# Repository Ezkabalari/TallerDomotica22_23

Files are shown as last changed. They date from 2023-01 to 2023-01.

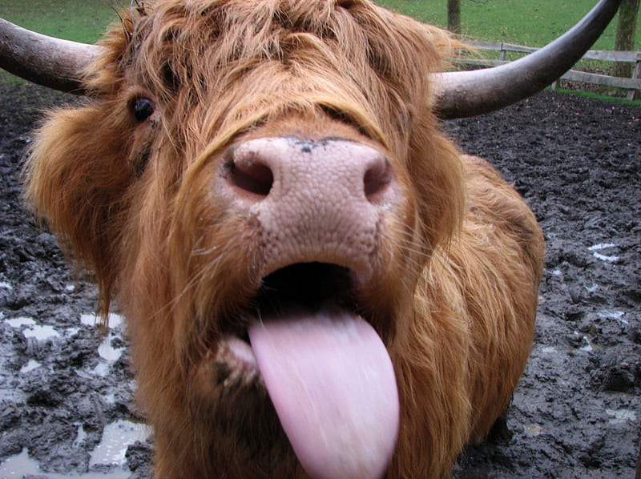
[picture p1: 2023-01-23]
RPi_HMI/web_ui/images/highcow.jpg

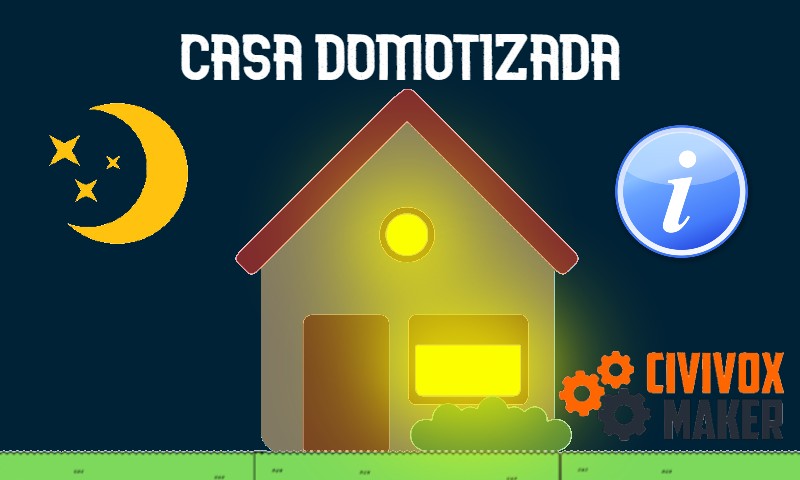
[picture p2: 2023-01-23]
imagenes/1 -2.jpg

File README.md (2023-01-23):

# TallerDomotica22_23
Smart Home

Sketches y scripts del taller de domótica dado en Civivox Mendillorri de Octubre 2022 a Febrero 2023. Para la creación de una maqueta de una casa inteligente.
Tambien se añade una carpeta para recrear la Funcionalidad de la pantalla de control en una pagina web alojada en una raspberry pi.

# Enlaces Interesantes
* Controlar un motor de pasos: https://github.com/cv47522/nodejs-j5-arduino-stepper
* Plataforma para controlar Placas como arduino desde una web con Javascript: https://johnny-five.io/

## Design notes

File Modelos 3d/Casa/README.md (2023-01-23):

Estos modelos 3D han sido creados por Aimar Romeo en Autodesk Inventor 2019.
Impresos en PLA de SmartMaterials (PLA Recycled azul claro) con los siguientes parámetros:

Impresoras: Clon Prusa MK3S+ con marco BEAR y Artillery Sidewinder X1 (Extrusor E3D Hemera).
Boquilla: 	0.4mm
Altura de capa: 0.2mm
Relleno: 	15%
Velocidad: 	60mm/s
Temperatura: 	200ºC
Soportes:	Sí. En todos los sitios.

Nota: Los modelos están escalados para imprimir una casa de 400x400mm

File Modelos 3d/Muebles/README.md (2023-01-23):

Estos modelos 3D han sido creados por Argoroots y descargados desde Printables.com
Gracias a su trabajo por estos modelos 3D tan maravillosos.

Nota: Los modelos 3D están escalados al tamaño original de la casa (400x400mm)

Enlace a Printables: https://www.printables.com/es/model/112496-dollhouse-furniture/files

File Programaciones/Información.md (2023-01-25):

Utilizar las siguientes líneas para cambiar de fondo/imagen en cada pantalla de la nextion.

Si está configurada como fondo de la página: //Ésto es importante, de ser una imagen y no un fondo, los botones/textos/íconos... "Desaparecerán" de la pantalla
página.pic=id de la foto
menu.pic=0

Para mandar datos desde arduino:
Serial.print ("menu.pic=0");
Serial.write(0xff);
Serial.write(0xff);
Serial.write(0xff);

Si queremos cambiar el fondo según el valor del sensor:
if (valor_sensor >= valor_medio){
  Serial.print ("menu.pic=0");
  Serial.write(0xff);
  Serial.write(0xff);
  Serial.write(0xff);
}
else(){
  Serial.print ("menu.pic=1");
  Serial.write(0xff);
  Serial.write(0xff);
  Serial.write(0xff);
}

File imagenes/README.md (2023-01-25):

Imagenes creadas por Aimar Romeo para el proyecto de domótica en Civivox Mendillorri 2023

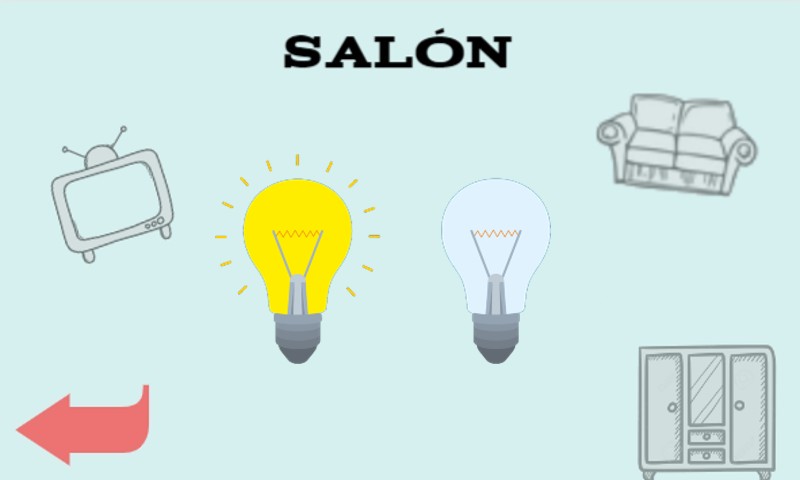
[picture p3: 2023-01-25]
imagenes/salon.jpg

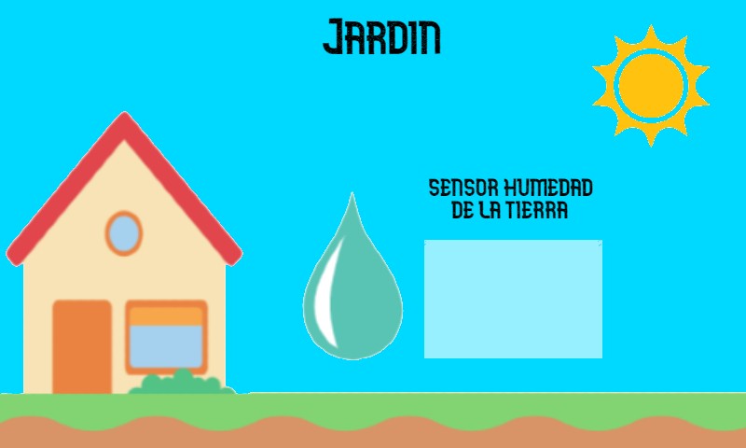
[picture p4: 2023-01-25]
imagenes/Jardin dia.jpg

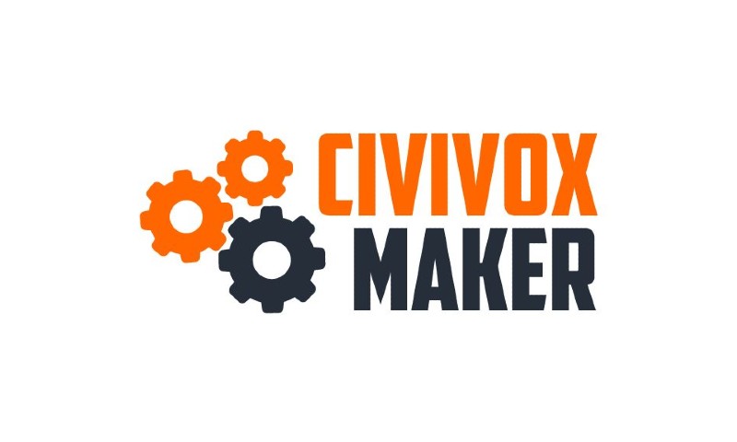
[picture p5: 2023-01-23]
imagenes/Pantalla de carga.jpg

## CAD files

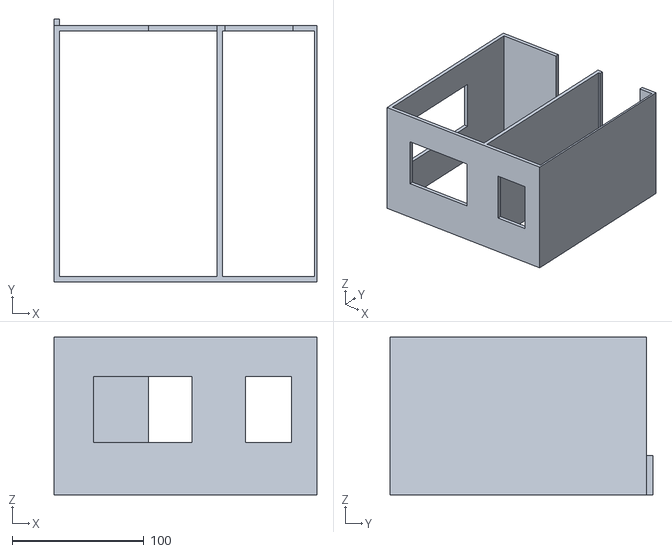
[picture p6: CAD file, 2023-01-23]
Modelos 3d/Casa/Parte 3.stl
200.0 x 200.0 x 120.0

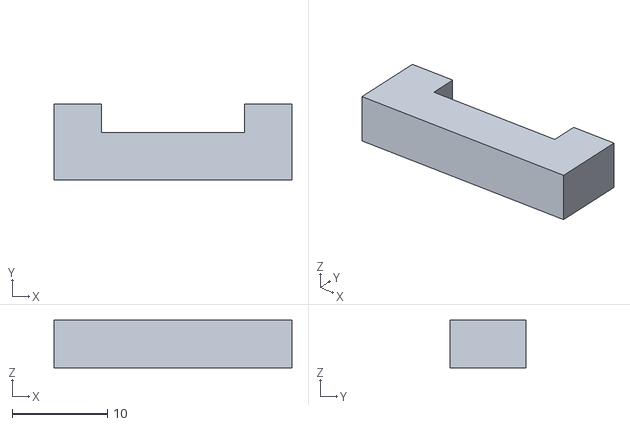
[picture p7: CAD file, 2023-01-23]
Modelos 3d/Muebles/Armario/Armario-Pata x2.stl
25.0 x 8.00 x 5.00

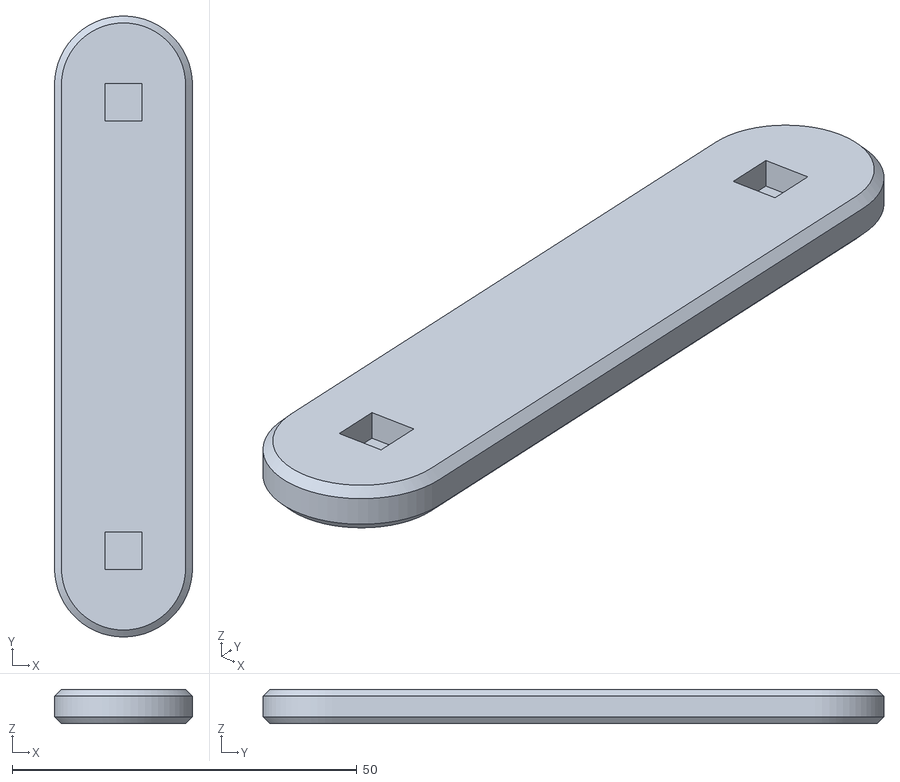
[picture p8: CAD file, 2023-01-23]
Modelos 3d/Muebles/Cama/Cama-Respaldo.stl
20.0 x 90.0 x 5.00

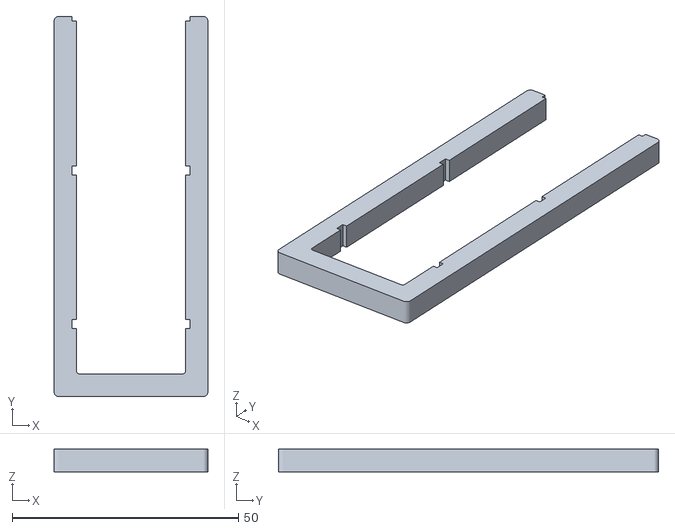
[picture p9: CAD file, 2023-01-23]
Modelos 3d/Muebles/Estantería/Estantería-Pata x2.stl
34.0 x 84.0 x 5.00

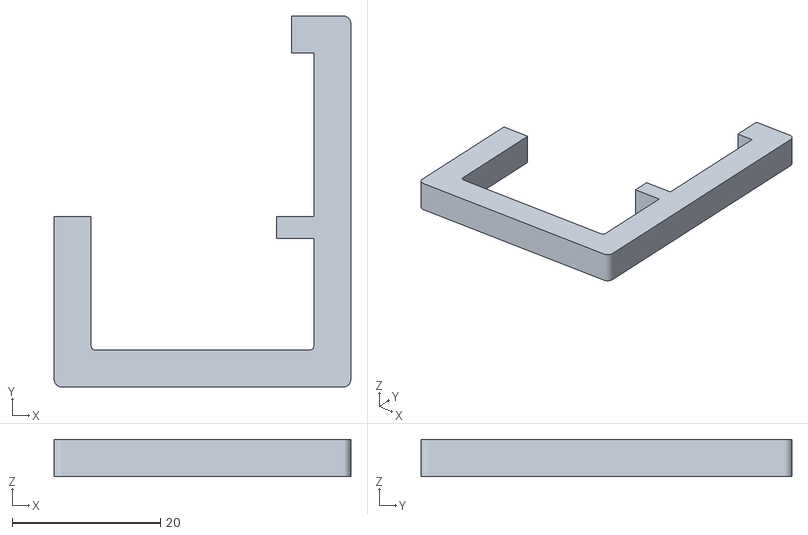
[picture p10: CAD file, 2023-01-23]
Modelos 3d/Muebles/Silla/Silla-Pata x2.stl
40.0 x 50.0 x 5.00

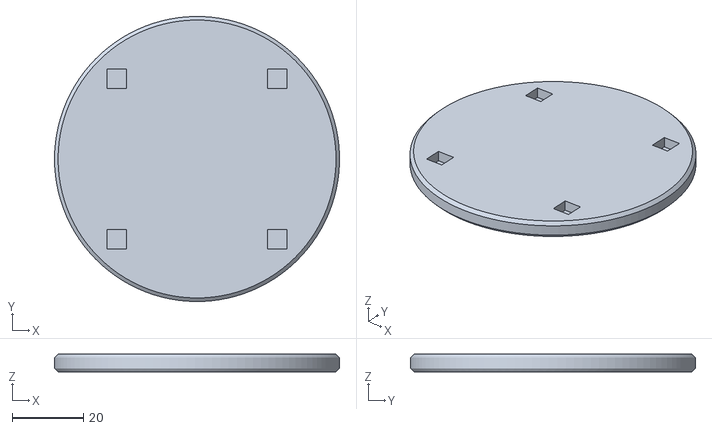
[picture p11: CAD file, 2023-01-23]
Modelos 3d/Muebles/Table/Mesa.stl
80.0 x 80.0 x 5.00

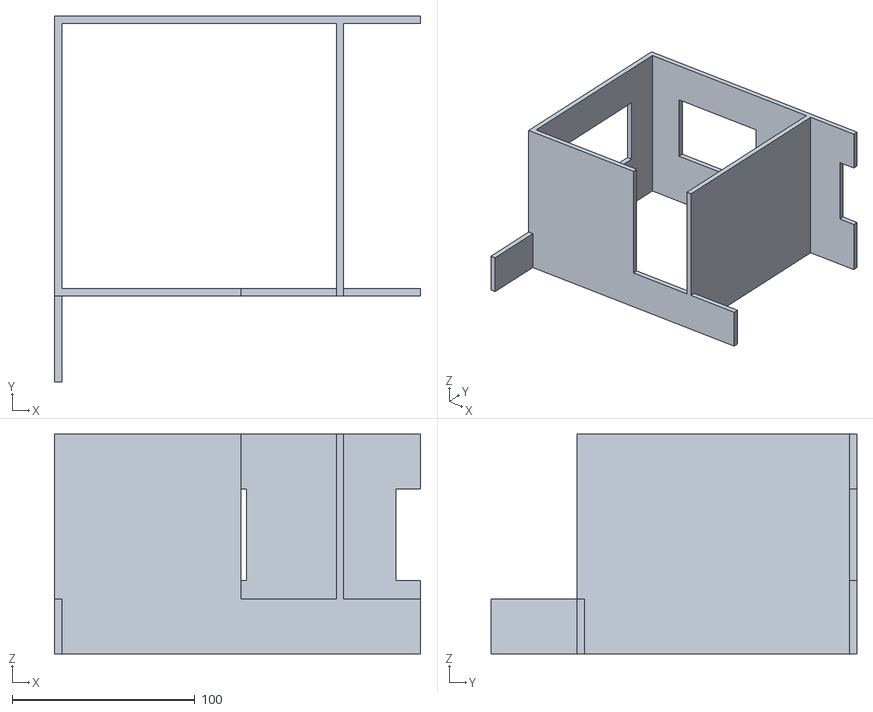
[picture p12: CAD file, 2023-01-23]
Modelos 3d/Casa/Parte 1.stl
200.0 x 200.0 x 120.0

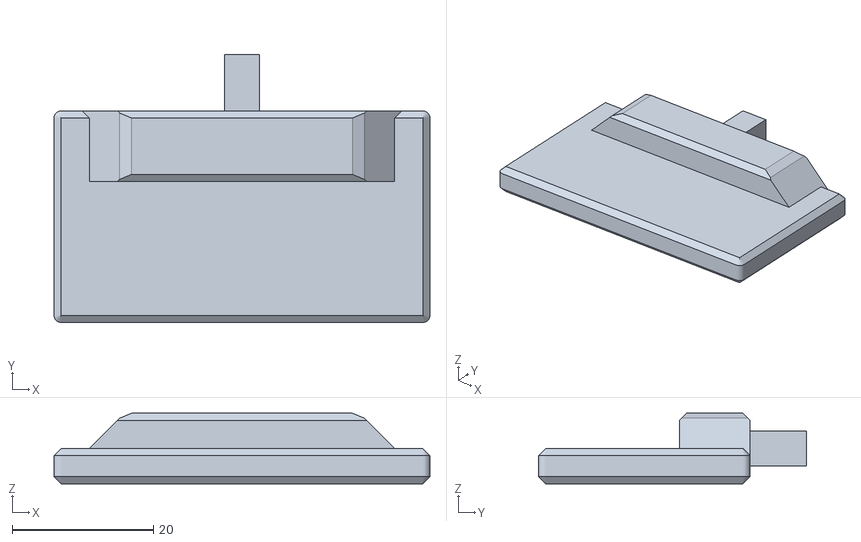
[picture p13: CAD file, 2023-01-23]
Modelos 3d/Muebles/Armario/Televisión.stl
53.3 x 38.0 x 10.0

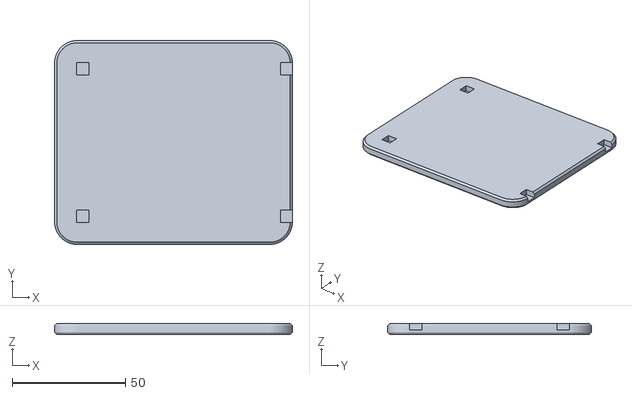
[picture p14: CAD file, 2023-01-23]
Modelos 3d/Muebles/Cama/Cama.stl
105.0 x 90.0 x 5.00

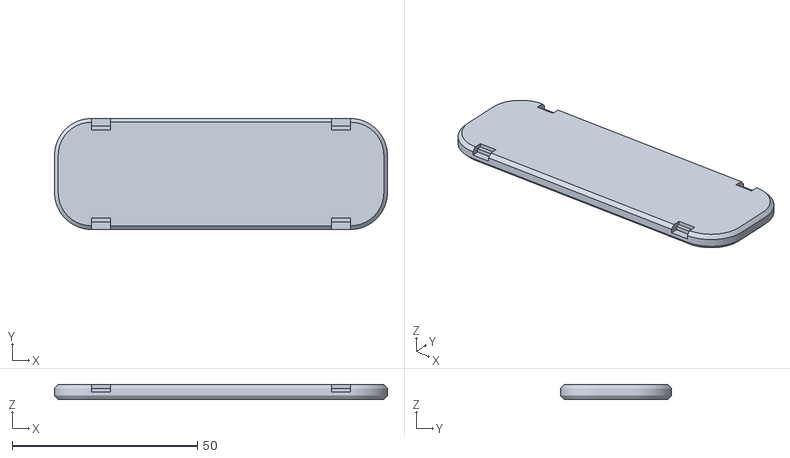
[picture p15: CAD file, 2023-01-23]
Modelos 3d/Muebles/Estantería/Estantería-Superior.stl
90.0 x 30.0 x 4.00

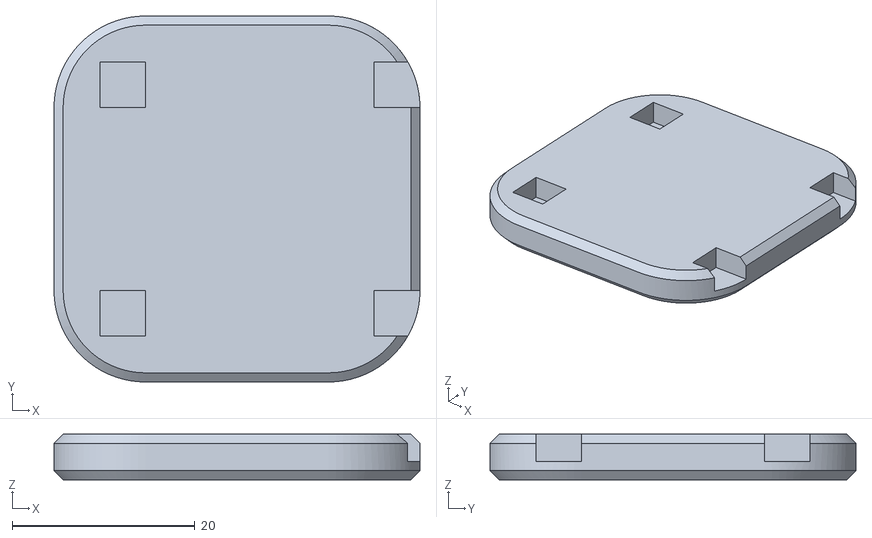
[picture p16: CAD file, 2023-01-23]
Modelos 3d/Muebles/Silla/Silla.stl
40.0 x 40.0 x 5.00

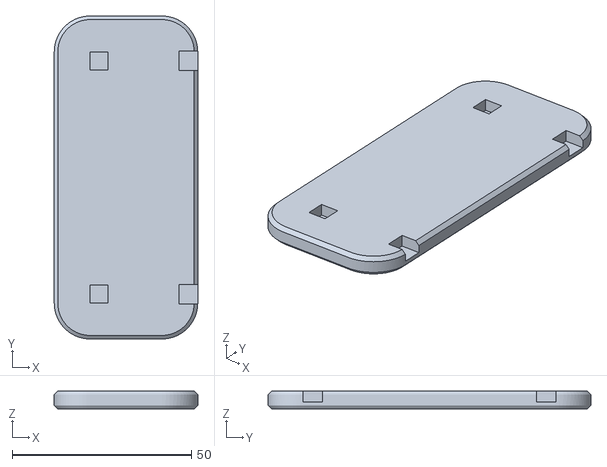
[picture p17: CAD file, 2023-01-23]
Modelos 3d/Muebles/Sofa/Sofa.stl
40.0 x 90.0 x 5.00

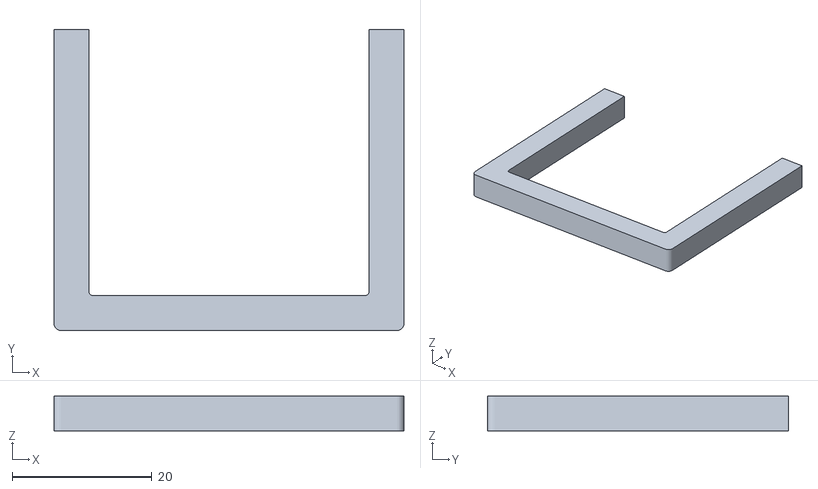
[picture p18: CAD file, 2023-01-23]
Modelos 3d/Muebles/Table/Mesa-Pata x2.stl
50.0 x 43.0 x 5.00

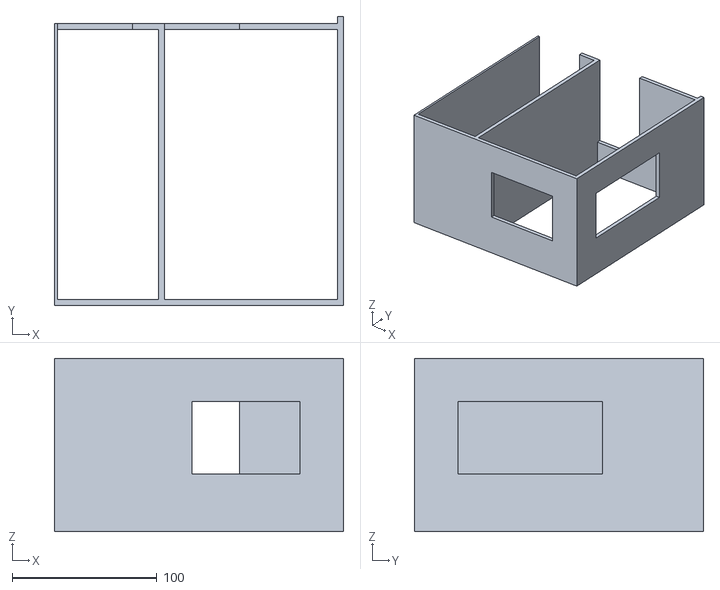
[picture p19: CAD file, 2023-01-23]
Modelos 3d/Casa/Parte 4.stl
200.0 x 200.0 x 120.0

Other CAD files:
Modelos 3d/Muebles/Armario/Armario.stl
Modelos 3d/Muebles/Cama/Cama-Pata x2.stl
Modelos 3d/Muebles/Estantería/Estantería.stl
Modelos 3d/Casa/Casa - Proyecto Inventor 2019.ipt
Modelos 3d/Casa/Casa completa.stl
Modelos 3d/Casa/Parte 2.stl
Modelos 3d/Muebles/Silla/Silla-Respaldo.stl
Modelos 3d/Muebles/Sofa/Sofa-Almohada x2.stl
Modelos 3d/Muebles/Sofa/Sofa-Pata x2.stl

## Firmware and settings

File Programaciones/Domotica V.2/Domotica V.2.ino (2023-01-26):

/*
 * Pines de conexionado a arduino UNO:
 * 
 * A0: Sensor de gas para la cocina           (MQ-02)
 * A1: Sensor de humedad de la tierra         (Higrometro V1.2)
 * A2: Sensor de luz para garaje              (KY-018)
 * A3: Sensor de luz para exterior            (KY-018)
 * A4: Sensor de temperatura de habitación 1  (LM35)
 * A5: ///////////////////////////////////////////////////////////////////////////////////////////////
 * D0: Nextion cable azul                     (Nextion NX8048T050)
 * D1: Nextion cable amarillo                 (Nextion NX8048T050)
 * D2: Leds Habitación 1                      (Led amarillo 5mm)
 * D3: Leds Baño                              (Led amarillo 5mm)
 * D4: Leds Cuarto lavadora                   (Led amarillo 5mm)
 * D5: Leds Habitación 2                      (Led amarillo 5mm)
 * D6: Leds Pasillo                           (Led amarillo 5mm)
 * D7: Leds Cocina                            (Led amarillo 5mm)
 * D8: Leds Salón                             (Led amarillo 5mm)
 * D9: Leds Gimnasio                          (Led amarillo 5mm)
 * D10: Sensor de presencia del pasillo       (HC-SR505)
 * D11: Servomotor de la puerta principal     (SG-90)
 * D12: Ventilador de la habitación 1         (Noctua NF-A4x10)
 * D13: Bomba de agua de la tierra            (Bomba de agua de 12v)
 */

/* 
DATOS MANDADOS DE NEXTION A ARDUINO

NAME     |  ON    |  OFF   |  description
=====================================================
lall     |  100   |  101   |  luces de toda la casa
lh1      |  102   |  103   |  luces habitación 1
lwc      |  104   |  105   |  luces baño
llav     |  106   |  107   |  luces lavadora
lh2      |  108   |  109   |  luces habitación 2
lco      |  110   |  111   |  luces cocina
lpas     |  112   |  113   |  luces pasillo
lgym     |  114   |  115   |  luces gimnasio
lsal     |  116   |  117   |  luces salón
bven     |  200   |        |  botón ventilador
bag      |  201   |        |  botón agua
bpu      |  202   |        |  botón puerta
bal      |  203   |  204   |  botón alarma



DATOS MANDADOS DE ARDUINO A NEXTION
variable |    sensor   | lugar
=======================================
stem     | temperatura | habitación 1
sgas     |     gas     | cocina
ssum     |   humedad   | jardín
spir     |  movimiento | pasillo
sldr     |     LDR     | menú
sppal    |     LDR     | puerta principal

*/
// LIBRERÍAS
#include <Servo.h>


//PINES UTILIZADOS
int rele_bomba = 13;                              //Configuramos la salida digital 13 para el relé que controla la bomba de agua
int rele_ventilador = 12;                         //Configuramos la salida digital 12 para el relé que controla el ventilador
Servo puerta_principal;                           //Los servos se configuran en el void setup
int sensor_PIR = 10;                              //Configuramos la entrada digital 4 para el sensor de movimiento
int led_gimnasio = 9;                             //Configuramos la salida digital 9 para la luz del gimnasio
int led_salon = 8;                                //Configuramos la salida digital 8 para la luz del salón
int led_cocina = 7;                               //Configuramos la salida digital 7 para la luz de la cocina
int led_pasillo = 6;                              //Configuramos la salida digital 6 para la luz del pasillo
int led_hab2 = 5;                                 //Configuramos la salida digital 5 para la luz de la habitación 2
int led_lavadora = 4;                             //Configuramos la salida digital 4 para la luz del cuarto de la lavadora
int led_wc = 3;                                   //Configuramos la salida digital 3 para la luz del baño
int led_hab1 = 2;                                 //Configuramos la salida digital 2 para la luz de la habitación 1
// Pin 1 reservado para Nextion                   //Arduino trae por defecto éste pin para la transmisión de datos
// Pin 0 reservado para Nextion                   //Arduino trae por defecto éste pin para la recepción de datos
int sensor_temperatura = A4;                      //Configuramos la entrada analógica 4 para el sensor de temperatura
int sensor_luz = A3;                              //Configuramos la entrada analógica 3 para el sensor de luz
int sensor_puerta = A2;                           //Configuramos la entrada analógica 2 para el sensor de luz
int sensor_tierra = A1;                           //Configuramos la entrada analógica 1 para el sensor de humedad
int sensor_gas = A0;                              //Configuramos la entrada analógica 0 para el sensor de gas

int Valarma = 0;

void setup() {
  Serial.begin (9600);                            //Iniciamos la comunicación serial a 9600 baudios para la comunicación con la pantalla Nextion
  pinMode (rele_bomba, OUTPUT);                   //Definimos como SALIDA el pin conectado al relé que controla la bomba de agua
  pinMode (rele_ventilador, OUTPUT);              //Definimos como SALIDA el pin conectado al relé que controla el ventilador
  puerta_principal.attach (11);                   //Configuramos la SALIDA 11 para el servo de la puerta principal
  pinMode (led_gimnasio, OUTPUT);                 //Definimos como SALIDA el pin conectado a la luz del gimnasio
  pinMode (led_salon, OUTPUT);                    //Definimos como SALIDA el pin conectado a la luz del salon
  pinMode (led_cocina, OUTPUT);                   //Definimos como SALIDA el pin conectado a la luz de la cocina
  pinMode (led_pasillo, OUTPUT);                  //Definimos como SALIDA el pin conectado a la luz del pasillo
  pinMode (led_hab2, OUTPUT);                     //Definimos como SALIDA el pin conectado a la luz de la habitación 2
  pinMode (led_lavadora, OUTPUT);                 //Definimos como SALIDA el pin conectado a la luz del cuarto de la lavadora
  pinMode (led_wc, OUTPUT);                       //Definimos como SALIDA el pin conectado a la luz del baño
  pinMode (led_hab1, OUTPUT);                     //Definimos como SALIDA el pin conectado a la luz de la habitación 1
  pinMode (sensor_temperatura, INPUT);            //Definimos como ENTRADA el pin conectado al sensor de temperatura
  pinMode (sensor_PIR, INPUT);                    //Definimos como ENTRADA el pin conectado al sensor de presencia
  pinMode (sensor_luz, INPUT);                    //Definimos como ENTRADA el pin conectado al sensor de luz del exterior
  pinMode (sensor_puerta, INPUT);                 //Definimos como ENTRADA el pin conectado al sensor de luz de la puerta principal
  pinMode (sensor_tierra, INPUT);                 //Definimos como ENTRADA el pin conectado al sensor de humedad de la tierra
  pinMode (sensor_gas, INPUT);                    //Definimos como ENTRADA el pin conectado al sensor de gases


  puerta_principal.write(0);                      //Movemos el servomotor a su posición inicial
  digitalWrite (led_gimnasio, LOW);               //Apagamos los leds del gimnasio
  digitalWrite (led_salon, LOW);                  //Apagamos los leds del salón
  digitalWrite (led_cocina, LOW);                 //Apagamos los leds de la cocina
  digitalWrite (led_pasillo, LOW);                //Apagamos los leds del pasillo
  digitalWrite (led_hab2, LOW);                   //Apagamos los leds de la habitación 2
  digitalWrite (led_lavadora, LOW);               //Apagamos los leds del cuarto de la lavadora
  digitalWrite (led_wc, LOW);                     //Apagamos los leds del baño
  digitalWrite (led_hab1, LOW);                   //Apagamos los leds de la habitación 1
  
}

void loop() {
  int Vstem = analogRead (sensor_temperatura);    //Definimos una variable a la cual asignamos el valor de lectura del sensor de temperatura
  int Vspir = analogRead (sensor_PIR);            //Definimos una variable a la cual asignamos el valor de lectura del sensor de movimiento
  int Vsldr = analogRead (sensor_luz);            //Definimos una variable a la cual asignamos el valor de lectura del sensor de luz exterior
  int Vsppal = analogRead (sensor_puerta);        //Definimos una variable a la cual asignamos el valor de lectura del sensor de luz entrada
  int Vshum = analogRead (sensor_tierra);         //Definimos una variable a la cual asignamos el valor de lectura del sensor de humedad del suelo
  int Vsgas = analogRead (sensor_gas);            //Definimos una variable a la cual asignamos el valor de lectura del sensor de gas
  int milivoltios = (Vstem / 1023.0) * 5000;
  int Vstemm = (milivoltios / 10);
  int Vdalarma = digitalRead (sensor_PIR);
  int estado_pir = LOW;
  
  String lectura = Serial.readString();           //Definimos la variable lectura que será con la cual recogeremos el valor de la pantalla
  
  if (int(lectura[0]) == 100){
      digitalWrite (led_gimnasio, HIGH);          //Encendemos los leds del gimnasio
      digitalWrite (led_salon, HIGH);             //Encendemos los leds del salón
      digitalWrite (led_cocina, HIGH);            //Encendemos los leds de la cocina
      digitalWrite (led_pasillo, HIGH);           //Encendemos los leds del pasillo
      digitalWrite (led_hab2, HIGH);              //Encendemos los leds de la habitación 2
      digitalWrite (led_lavadora, HIGH);          //Encendemos los leds del cuarto de la lavadora
      digitalWrite (led_wc, HIGH);                //Encendemos los leds del baño
      digitalWrite (led_hab1, HIGH);              //Encendemos los leds de la habitación 1
    }
  if (int(lectura[0]) == 101){
      digitalWrite (led_gimnasio, LOW);           //Apagamos los leds del gimnasio
      digitalWrite (led_salon, LOW);              //Apagamos los leds del salón
      digitalWrite (led_cocina, LOW);             //Apagamos los leds de la cocina
      digitalWrite (led_pasillo, LOW);            //Apagamos los leds del pasillo
      digitalWrite (led_hab2, LOW);               //Apagamos los leds de la habitación 2
      digitalWrite (led_lavadora, LOW);           //Apagamos los leds del cuarto de la lavadora
      digitalWrite (led_wc, LOW);                 //Apagamos los leds del baño
      digitalWrite (led_hab1, LOW);               //Apagamos los leds de la habitación 1
    }
  if (int(lectura[0]) == 102){
      digitalWrite (led_hab1, HIGH);              //Encendemos los leds de la habitación 1
    }
  if (int(lectura[0]) == 103){
      digitalWrite (led_hab1, LOW);               //Apagamos los leds de la habitación 1
    }
  if (int(lectura[0]) == 104){
      digitalWrite (led_wc, HIGH);                //Encendemos los leds del baño
    }
  if (int(lectura[0]) == 105){
      digitalWrite (led_wc, LOW);                 //Apagamos los leds del baño
    }
  if (int(lectura[0]) == 106){
      digitalWrite (led_lavadora, HIGH);          //Encendemos los leds del cuarto de la lavadora
    }
  if (int(lectura[0]) == 107){
      digitalWrite (led_lavadora, LOW);           //Apagamos los leds del cuarto de la lavadora
    }
  if (int(lectura[0]) == 108){
      digitalWrite (led_hab2, HIGH);              //Encendemos los leds de la habitación 2
    }
  if (int(lectura[0]) == 109){
      digitalWrite (led_hab2, LOW);               //Apagamos los leds de la habitación 2
    }
  if (int(lectura[0]) == 110){
      digitalWrite (led_cocina, HIGH);            //Encendemos los leds de la cocina
    }
  if (int(lectura[0]) == 111){
      digitalWrite (led_cocina, LOW);             //Apagamos los leds de la cocina
    }
  if (int(lectura[0]) == 112){
      digitalWrite (led_pasillo, HIGH);           //Encendemos los leds del pasillo
    }
  if (int(lectura[0]) == 113){
      digitalWrite (led_pasillo, LOW);            //Apagamos los leds del pasillo
    }
  if (int(lectura[0]) == 114){
      digitalWrite (led_gimnasio, HIGH);          //Encendemos los leds del gimnasio
    }
  if (int(lectura[0]) == 115){
      digitalWrite (led_gimnasio, LOW);           //Apagamos los leds del gimnasio
    }
  if (int(lectura[0]) == 116){
      digitalWrite (led_salon, HIGH);             //Encendemos los leds del salón
    }
  if (int(lectura[0]) == 117){
      digitalWrite (led_salon, LOW);              //Apagamos los leds del salón
    }
  if (int(lectura[0]) == 200){
      digitalWrite (rele_ventilador, HIGH);       //Encendemos el relé del ventilador
      delay (5000);
      digitalWrite (rele_ventilador, LOW);        //Apagamos el relé del ventilador
    }
  if (int(lectura[0]) == 201){
      digitalWrite (rele_bomba, HIGH);            //Encendemos el relé de la bomba de agua
      delay (5000);
      digitalWrite (rele_bomba, LOW);             //Apagamos el relé de la bomba de agua
    }   
  if (int(lectura[0]) == 202){
      puerta_principal.write(90);                 //Movemos el servomotor a su posición abierta
      delay (2500);
      puerta_principal.write(0);                  //Movemos el servomotor a su posición cerrada
    }
  if (int(lectura[0]) == 203){
      Valarma = 1;                                //Asignamos un 1 al estado de la alarma
    }
  if (int(lectura[0]) == 204){
      Valarma = 0;                                //Asignamos un 0 al estado de la alarma
    }
  if (Valarma = 1){                               //Si el estado de la alarma es 1, entonces...
      if (Vdalarma == HIGH){                      //Si el sensor de movimiento detecta movimiento, entonces...
        digitalWrite (led_gimnasio, HIGH);        //Encendemos los leds del gimnasio
        digitalWrite (led_salon, HIGH);           //Encendemos los leds del salón
        digitalWrite (led_cocina, HIGH);          //Encendemos los leds de la cocina
        digitalWrite (led_pasillo, HIGH);         //Encendemos los leds del pasillo
        digitalWrite (led_hab2, HIGH);            //Encendemos los leds de la habitación 2
        digitalWrite (led_lavadora, HIGH);        //Encendemos los leds del cuarto de la lavadora
        digitalWrite (led_wc, HIGH);              //Encendemos los leds del baño
        digitalWrite (led_hab1, HIGH);            //Encendemos los leds de la habitación 1
        delay (100);                              //Espera de 0,1s para hacer parpadeo
        digitalWrite (led_gimnasio, LOW);         //Apagamos los leds del gimnasio
        digitalWrite (led_salon, LOW);            //Apagamos los leds del salón
        digitalWrite (led_cocina, LOW);           //Apagamos los leds de la cocina
        digitalWrite (led_pasillo, LOW);          //Apagamos los leds del pasillo
        digitalWrite (led_hab2, LOW);             //Apagamos los leds de la habitación 2
        digitalWrite (led_lavadora, LOW);         //Apagamos los leds del cuarto de la lavadora
        digitalWrite (led_wc, LOW);               //Apagamos los leds del baño
        digitalWrite (led_hab1, LOW);             //Apagamos los leds de la habitación 1
        delay (100);                              //Espera de 0,1s para hacer parpadeo
      }
      else {                                      //Sino...
        digitalWrite (led_gimnasio, LOW);         //Apagamos los leds del gimnasio
        digitalWrite (led_salon, LOW);            //Apagamos los leds del salón
        digitalWrite (led_cocina, LOW);           //Apagamos los leds de la cocina
        digitalWrite (led_pasillo, LOW);          //Apagamos los leds del pasillo
        digitalWrite (led_hab2, LOW);             //Apagamos los leds de la habitación 2
        digitalWrite (led_lavadora, LOW);         //Apagamos los leds del cuarto de la lavadora
        digitalWrite (led_wc, LOW);               //Apagamos los leds del baño
        digitalWrite (led_hab1, LOW);             //Apagamos los leds de la habitación 1
        }
    } 
    if(Vshum < 500)
    {
      digitalWrite (rele_bomba, HIGH);
      delay (5000);
      digitalWrite (rele_bomba, LOW);
    }
    if (Vsppal < 750){
      puerta_principal.write(90);                 //Movemos el servomotor a su posición abierta
      delay (2500);
      puerta_principal.write(0);                  //Movemos el servomotor a su posición cerrada
    }
    if (Vsgas < 750){
      puerta_principal.write(90);                 //Movemos el servomotor a su posición abierta
      delay (2500);
      puerta_principal.write(0);                  //Movemos el servomotor a su posición cerrada
    }
    if (Vsldr <= 400){
      Serial.print ("menu.pic=1");
      Serial.write(0xff);
      Serial.write(0xff);
      Serial.write(0xff);
    }
    else {
      Serial.print ("menu.pic=0");
      Serial.write(0xff);
      Serial.write(0xff);
      Serial.write(0xff);
    }
  delay (2500);
  
  Serial.print ("stem.val=");                     //Enviamos datos del sensor de temperatura a la pantalla
  Serial.print (Vstem);
  Serial.write(0xff);
  Serial.write(0xff);
  Serial.write(0xff);
  Serial.print ("stemm.val=");                    //Enviamos datos del sensor de temperatura (en celsius) a la pantalla
  Serial.print (Vstemm);
  Serial.write(0xff);
  Serial.write(0xff);
  Serial.write(0xff);
  Serial.print ("sgas.val=");                     //Enviamos datos del sensor de gas a la pantalla
  Serial.print (Vsgas);
  Serial.write(0xff);
  Serial.write(0xff);
  Serial.write(0xff);
  Serial.print ("shum.val=");                     //Enviamos datos del sensor de humedad a la pantalla
  Serial.print (Vshum);
  Serial.write(0xff);
  Serial.write(0xff);
  Serial.write(0xff);
  Serial.print ("spir.val=");                     //Enviamos datos del sensor de movimiento a la pantalla
  Serial.print (Vspir);
  Serial.write(0xff);
  Serial.write(0xff);
  Serial.write(0xff);
  Serial.print ("sppal.val=");                    //Enviamos datos del sensor de luz de la puerta principal a la pantalla
  Serial.print (Vsppal);
  Serial.write(0xff);
  Serial.write(0xff);
  Serial.write(0xff);
  Serial.print ("sldr.val=");                     //Enviamos datos del sensor de luz exterior a la pantalla
  Serial.print (Vsldr);
  Serial.write(0xff);
  Serial.write(0xff);
  Serial.write(0xff);
  
}

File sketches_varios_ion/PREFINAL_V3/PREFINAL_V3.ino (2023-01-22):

// Code copied from https://www.instructables.com/Controlling-a-Servo-With-an-Ultrasonic-Sensor-Usin/
// Include servo library. we can look up a for different libraries to control servo???
#include <Servo.h>

int rojo = 13;
int amarillo = 11;
int verde = 9;
// PWN pin 1 is to control servo (yellow-orange)
int servo_control = 2;
Servo servo; // Declare the servo variable
int sound = 250; // from 
// trigger SR04 PWN Pin 6
int triggerpin = 6;
// echo SR04 PWN Pin 4
int echopin = 4;
// here we declare pos as initial servo position for the angle in our case 145º
int pos0 = 145;
void setup() {
  Serial.begin (9600);
  pinMode(triggerpin, OUTPUT); // Set up trigger ping from ultrasonic sensor HC-SR04
  pinMode(echopin, INPUT);
  pinMode(rojo, OUTPUT);
  pinMode(amarillo, OUTPUT);
  pinMode(verde, OUTPUT);
  servo.attach(servo_control); // Attach to defined Pin connected to servo control cable
}
void loop() {
  servo.write(pos0);
  //delay(5000);
  // measure distance with HC-SR04 sensor
  long duration, distance;
  digitalWrite(triggerpin, LOW);
  delayMicroseconds(2);
  digitalWrite(triggerpin, HIGH);
  delayMicroseconds(10);
  digitalWrite(triggerpin, LOW);
  duration = pulseIn(echopin, HIGH);
  distance = (duration/2)/29.1;
  if (distance <12){
    Serial.print(distance);
    Serial.println(" cm");
    digitalWrite(verde, HIGH); 
    //delay(1000);
    //servo.write(90);
    for (pos = 145; pos <= 235; pos += 1) {
      // In steps on 1 degree
      servo.write(pos);
      delay(15);
      }
    delay(6000); // To allow the car to pass the barrier with sufficient time
    // Now we lower the barrier 
    for (pos = 235; pos <= 145; pos -= 1) {
      servo.write(pos);
      //digitalWrite(verde, LOW); // Green led stays lit all the loop
      delay(15);
    }
    digitalWrite(verde, LOW); 
  }
  else if (distance < 50){
    Serial.print(distance);
    Serial.println(" cm");
    digitalWrite(rojo, HIGH);
    //servo.write(145); //moves too fast
    for (pos = 235; pos <= 145; pos -= 1) {
      servo.write(pos);
      digitalWrite(rojo, LOW);
      delay(15);
    }
    //delay(2000);
    //digitalWrite(rojo, LOW);
  }
  else{
    Serial.println("The distance is more than 80cm.");
    digitalWrite(rojo, HIGH);
    servo.write(145); //moves too fast
    //delay(2000);
    digitalWrite(rojo, LOW);  
  }
  //delay(1000);
  // EXTRA CODE
  /*
  digitalWrite(amarillo, HIGH);
  delay(500);                
  digitalWrite(amarillo, LOW);  
  delay(500);
  */
  }  

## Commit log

2023-01-22 Añadidos scripts de comucicacion serie con us cable USB entre la RPi y arduino. Son de comunicacion unidirecional Arduino -> RPi
2023-01-23 Añadidos archivos de Aimar, una version preliminar.
    [Armario-Pata x2.stl, Armario.stl, Cama-Pata x2.stl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]
2023-01-24 Rename Programaciones/probar_cambio_de_fondos_de_pantalla.ino to Programaciones/Prueba - Envio de datos/probar_cambio_de_fondos_de_pantalla.ino
